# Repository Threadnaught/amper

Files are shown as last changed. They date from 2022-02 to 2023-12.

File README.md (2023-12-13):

# Amper

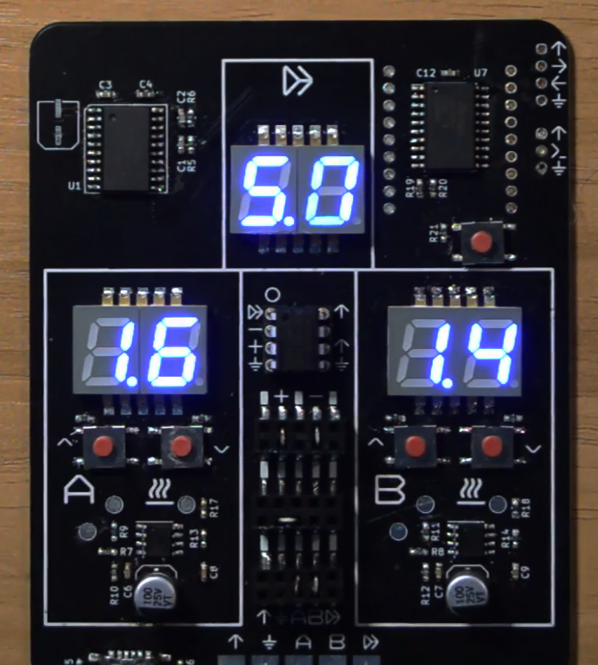
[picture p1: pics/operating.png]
Operating


I'm unprivating my amper project for posterity. At time of writing, a lot of the code looks commented out and it's been like two years so I dare not go back in now. It's got two basic functions:

1. A learning tool for Op-Amps allowing you to set two voltage rails and create a circuit on the breadboard-like arangement of headers in the middle.
2. A (somewhat bad) dual rail switch mode lab supply

1 worked relatively well. Turns out pin headers are designed more for du-pont style pins than resistor or capacitor legs.

Regarding 2, This project taught me a lesson: don't use a microcontroller to manage power rails unless you really know what you're doing. There are many things which can raise input impeadance too fast for a UC to notice, and then the rail will spike to supply voltage.

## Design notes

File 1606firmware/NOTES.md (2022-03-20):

 - https://github.com/ElTangas/jtag2updi
 - AVR-GCC
 - http://packs.download.atmel.com/ grab `Atmel ATtiny Series Device Support (1.10.348)`
 - Follow this tutorial http://leonerds-code.blogspot.com/2020/11/building-for-new-atmega-0-series-chips.html
 - MAY ALSO HAVE TO DO THE `/usr/avr/include/avr/io.h` STEP FROM THIS ONE https://gist.github.com/goncalor/51e1c8038cc058b4379552477255b4e1

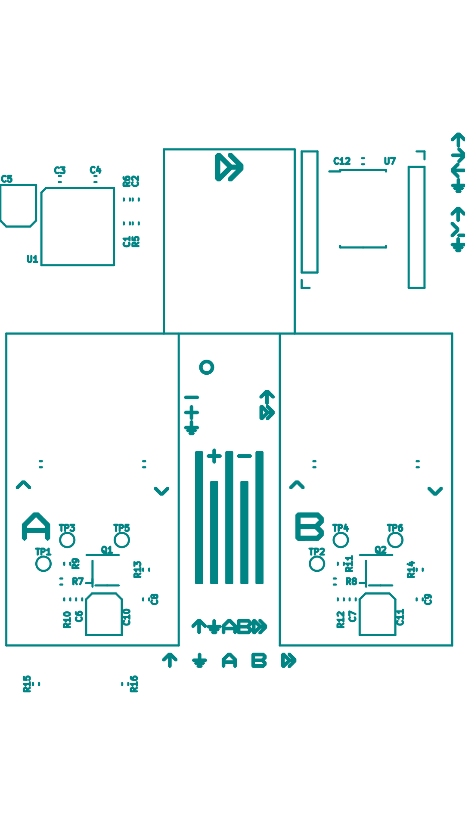
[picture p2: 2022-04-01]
kicad/pcb-plots/amper-F_SilkS.png

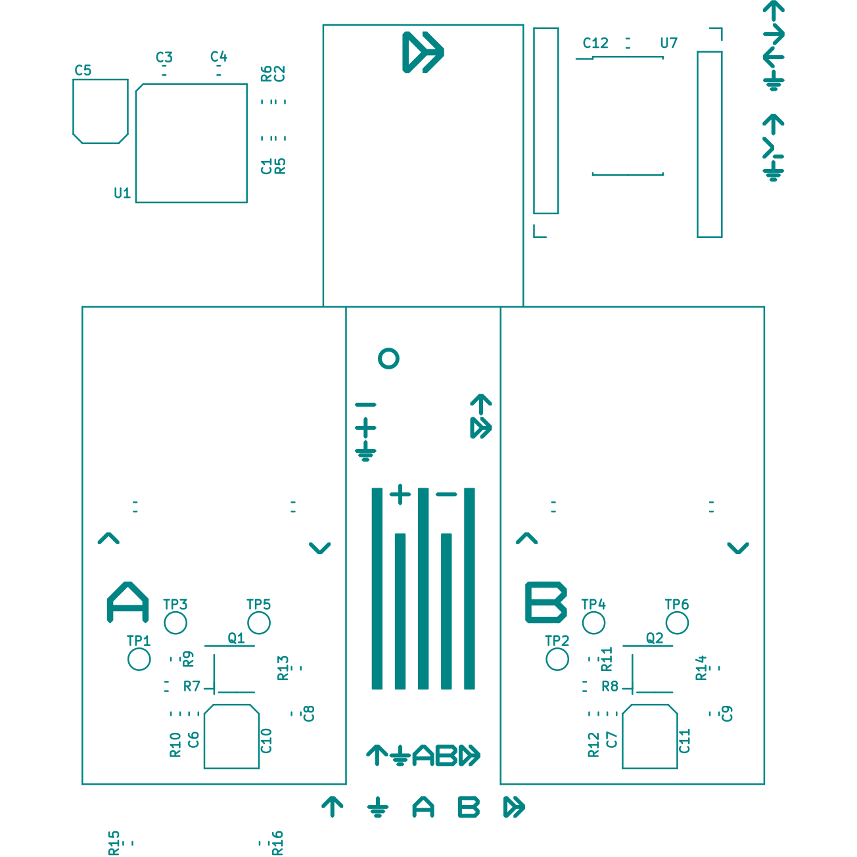
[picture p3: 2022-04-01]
kicad/pcb-plots/amper-F_SilkS-square.png

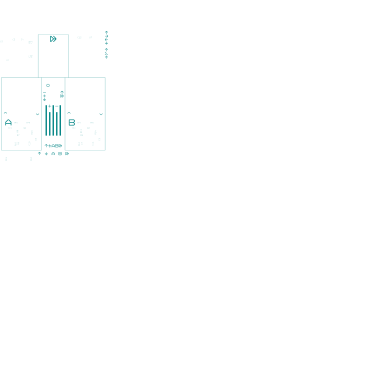
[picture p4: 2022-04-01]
kicad/pcb-plots/outp.png

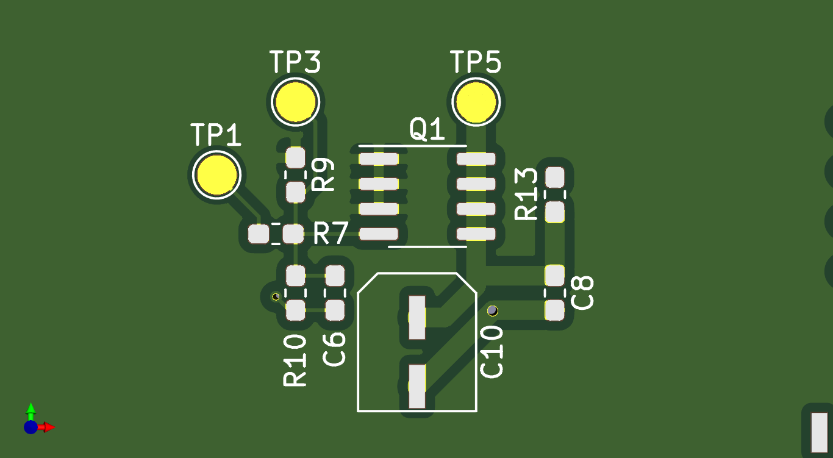
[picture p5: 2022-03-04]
kicad/amper/amper.png

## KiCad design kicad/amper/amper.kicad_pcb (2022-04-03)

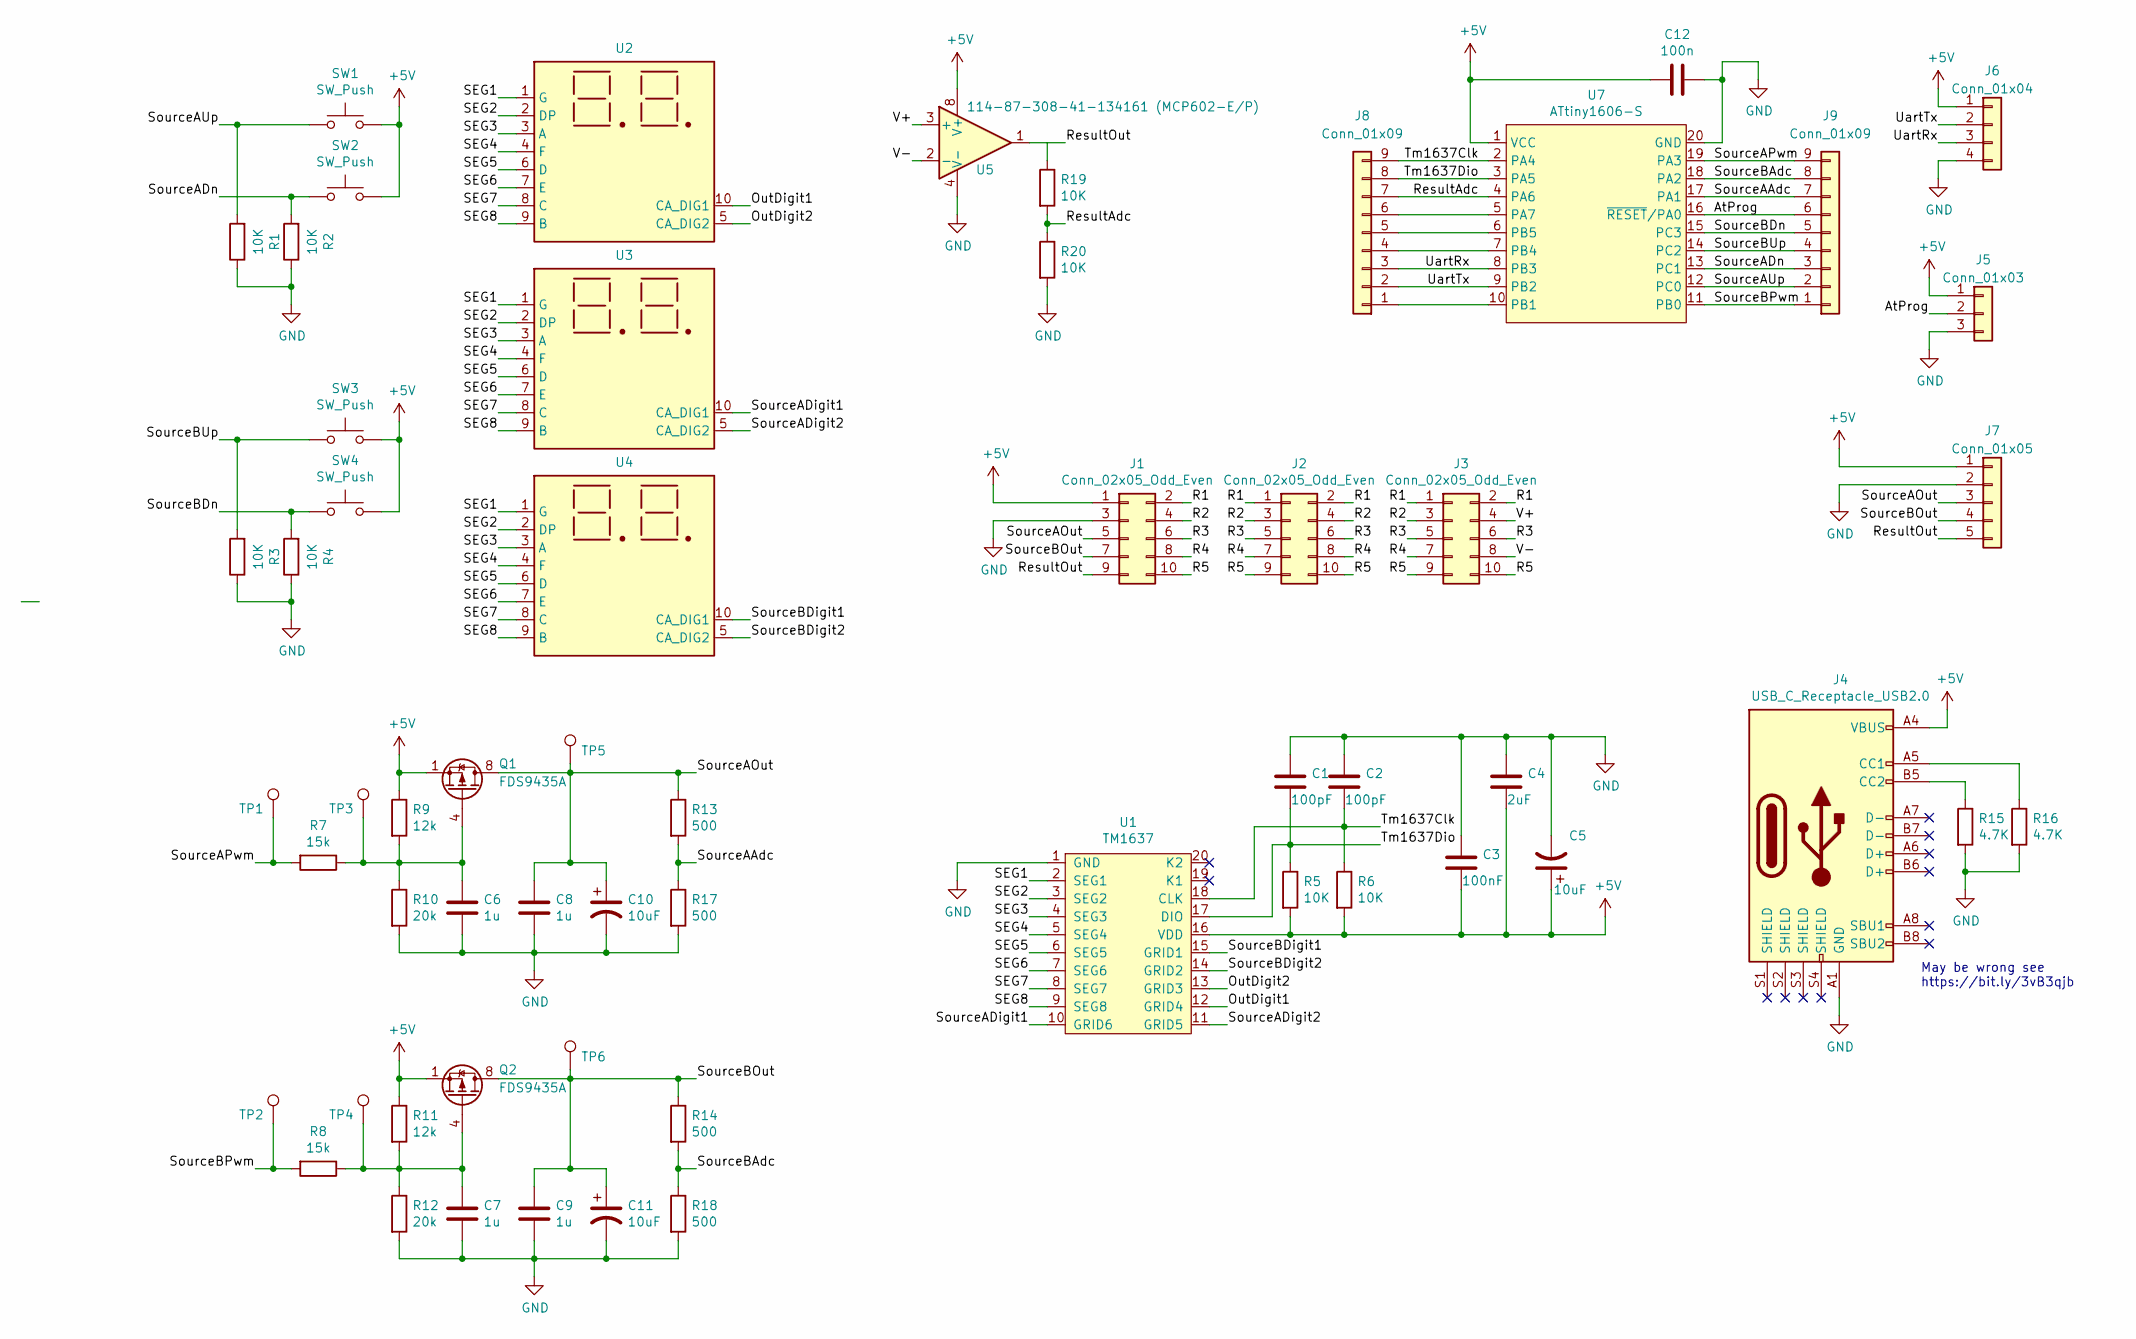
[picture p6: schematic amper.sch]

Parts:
C1, C2: 100pF; C_0603_1608Metric_Pad1.05x0.95mm_HandSolder
C3: 100nF; C_0603_1608Metric_Pad1.05x0.95mm_HandSolder
C4: 2uF; C_0603_1608Metric_Pad1.05x0.95mm_HandSolder; Part C85713
C5, C10, C11: 10uF; VT1H100M-CRD54; Part C305359
C6, C7, C8, C9: 1u; C_0603_1608Metric_Pad1.05x0.95mm_HandSolder
C12: 100n; C_0603_1608Metric_Pad1.05x0.95mm_HandSolder
J1: Conn_02x05_Odd_Even; 2.54_2x5_alternate-source-side
J2: Conn_02x05_Odd_Even; 2.54_2x5_alternate
J3: Conn_02x05_Odd_Even; 2.54_2x5_alternate-opamp-side
J4: USB_C_Receptacle_USB2.0; MC-303S
J5: Conn_01x03; PROG
J6: Conn_01x04; UART
J7: Conn_01x05; SolderHeader
J8, J9: Conn_01x09; PinSocket_1x09_P2.54mm_Vertical_no_silk
Q1, Q2: FDS9435A; SOIC-8_3.9x4.9mm_P1.27mm; Part C181098
R1, R2, R3, R4, R5, R6, R19, R20: 10K; R_0603_1608Metric_Pad1.05x0.95mm_HandSolder
R7, R8: 15k; R_0603_1608Metric_Pad1.05x0.95mm_HandSolder
R9, R11: 12k; R_0603_1608Metric_Pad1.05x0.95mm_HandSolder
R10, R12: 20k; R_0603_1608Metric_Pad1.05x0.95mm_HandSolder
R13, R14, R17, R18: 500; R_0603_1608Metric_Pad1.05x0.95mm_HandSolder
R15, R16: 4.7K; R_0603_1608Metric_Pad1.05x0.95mm_HandSolder
SW1, SW3: SW_Push; UpSwitch; Part C2909692
SW2, SW4: SW_Push; DnSwitch; Part C2909692
TP1, TP2, TP3, TP4, TP5, TP6: TestPoint; TestPoint_Pad_D2.0mm
U1: TM1637; Part C20001
U2, U3, U4: HDSM-441B; SLS0392FB4A1GD; Part C226000
U5: 114-87-308-41-134161 (MCP602-E/P); 114-87-308-41-134161-generated
U7: ATtiny1606-S; SOIC-20W_7.5x12.8mm_P1.27mm

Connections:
+5V: C3.2, C4.2, C5.1, C12.2, J1.1, J4.A4 (VBUS), J4.A9 (VBUS), J4.B4 (VBUS), J4.B9 (VBUS), J5.1, J6.1, J7.1, Q1.1 (S), Q1.2 (S), Q1.3 (S), Q2.1 (S), Q2.2 (S), Q2.3 (S), R5.2, R6.2, R9.1, R11.1, SW1.2, SW2.2, SW3.2, SW4.2, U1.16 (VDD), U5.6 (NULL), U5.8 (V+), U7.1 (VCC)
/AtProg: J5.2, J9.6, U7.16 (~RESET~/PA0)
/OutDigit1: U1.12 (GRID4), U2.10 (CA_DIG1)
/OutDigit2: U1.13 (GRID3), U2.5 (CA_DIG2)
/R1: J1.2, J2.1, J2.2, J3.1, J3.2
/R2: J1.4, J2.3, J2.4, J3.3
/R3: J1.6, J2.5, J2.6, J3.5, J3.6
/R4: J1.8, J2.7, J2.8, J3.7
/R5: J1.10, J2.9, J2.10, J3.9, J3.10
/ResultAdc: J8.7, R19.2, R20.1, U7.4 (PA6)
/ResultOut: J1.9, J7.5, R19.1, U5.1
/SEG1: U1.2 (SEG1), U2.1 (G), U3.1 (G), U4.1 (G)
/SEG2: U1.3 (SEG2), U2.2 (DP), U3.2 (DP), U4.2 (DP)
/SEG3: U1.4 (SEG3), U2.3 (A), U3.3 (A), U4.3 (A)
/SEG4: U1.5 (SEG4), U2.4 (F), U3.4 (F), U4.4 (F)
/SEG5: U1.6 (SEG5), U2.6 (D), U3.6 (D), U4.6 (D)
/SEG6: U1.7 (SEG6), U2.7 (E), U3.7 (E), U4.7 (E)
/SEG7: U1.8 (SEG7), U2.8 (C), U3.8 (C), U4.8 (C)
/SEG8: U1.9 (SEG8), U2.9 (B), U3.9 (B), U4.9 (B)
/SourceAAdc: J9.7, R13.2, R17.1, U7.17 (PA1)
/SourceADigit1: U1.10 (GRID6), U3.10 (CA_DIG1)
/SourceADigit2: U1.11 (GRID5), U3.5 (CA_DIG2)
/SourceADn: J9.3, R2.2, SW2.1, U7.13 (PC1)
/SourceAOut: C8.1, C10.1, J1.5, J7.3, Q1.5 (D), Q1.6 (D), Q1.7 (D), Q1.8 (D), R13.1, TP5.1
/SourceAPwm: J9.9, R7.2, TP1.1, U7.19 (PA3)
/SourceAUp: J9.2, R1.2, SW1.1, U7.12 (PC0)
/SourceBAdc: J9.8, R14.2, R18.1, U7.18 (PA2)
/SourceBDigit1: U1.15 (GRID1), U4.10 (CA_DIG1)
/SourceBDigit2: U1.14 (GRID2), U4.5 (CA_DIG2)
/SourceBDn: J9.5, R4.2, SW4.1, U7.15 (PC3)
/SourceBOut: C9.1, C11.1, J1.7, J7.4, Q2.5 (D), Q2.6 (D), Q2.7 (D), Q2.8 (D), R14.1, TP6.1
/SourceBPwm: J9.1, R8.2, TP2.1, U7.11 (PB0)
/SourceBUp: J9.4, R3.2, SW3.1, U7.14 (PC2)
/Tm1637Clk: C2.2, J8.9, R6.1, U1.18 (CLK), U7.2 (PA4)
/Tm1637Dio: C1.2, J8.8, R5.1, U1.17 (DIO), U7.3 (PA5)
/UartRx: J6.3, J8.3, U7.8 (PB3)
/UartTx: J6.2, J8.2, U7.9 (PB2)
/V+: J3.4, U5.3 (+)
/V-: J3.8, U5.2 (-)
GND: C1.1, C2.1, C3.1, C4.1, C5.2, C6.2, C7.2, C8.2, C9.2, C10.2, C11.2, C12.1, J1.3, J4.A1 (GND), J4.A12 (GND), J4.B1 (GND), J4.B12 (GND), J5.3, J6.4, J7.2, R1.1, R2.1, R3.1, R4.1, R10.2, R12.2, R15.2, R16.2, R17.2, R18.2, R20.2, U1.1 (GND), U5.4 (V-), U5.5 (NULL), U7.20 (GND)
unnamed: C6.1, Q1.4 (G), R7.1, R9.2, R10.1, TP3.1
unnamed: C7.1, Q2.4 (G), R8.1, R11.2, R12.1, TP4.1
unnamed: J4.A5 (CC1), R16.1
unnamed: J4.B5 (CC2), R15.1
unnamed: J8.1, U7.10 (PB1)
unnamed: J8.4, U7.7 (PB4)
unnamed: J8.5, U7.6 (PB5)
unnamed: J8.6, U7.5 (PA7)

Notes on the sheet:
May be wrong see https://bit.ly/3vB3qjb

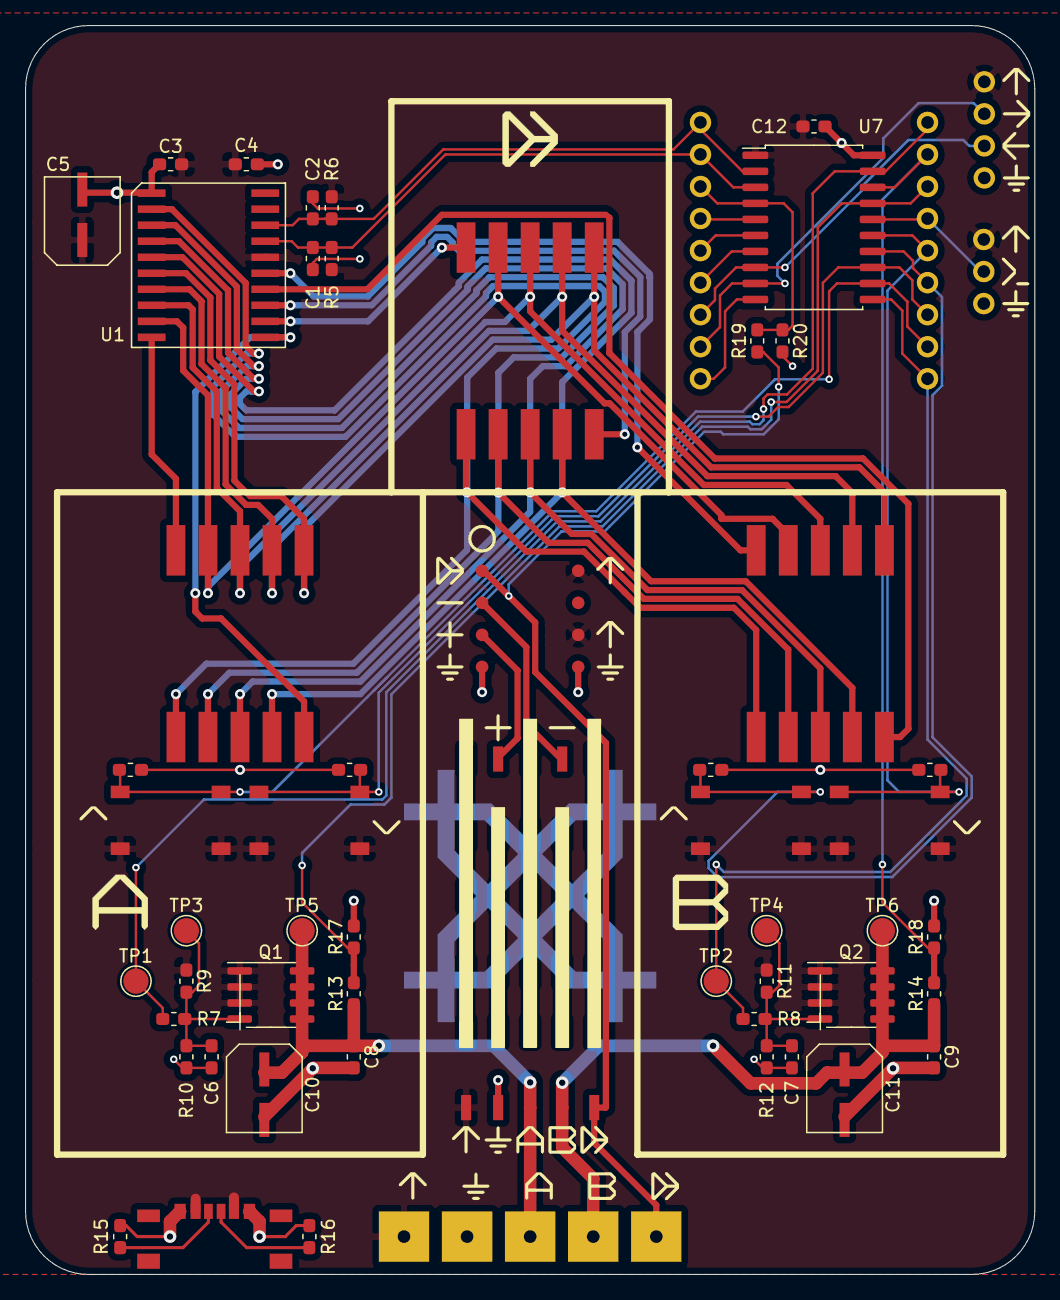
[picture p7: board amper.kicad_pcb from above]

Board: 2 copper layers, 80.0 x 99.0 mm, 63 parts (1 on the bottom side), 48 nets.

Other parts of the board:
svg2mod: G***; pcb_logo_small
svg2mod#2: G***; LargeOutput
svg2mod#3: G***; LargeB
svg2mod#4: G***; LargeA

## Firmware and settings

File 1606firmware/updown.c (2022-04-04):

#ifndef __AVR_ATtiny1606__
#define __AVR_ATtiny1606__
#endif

#include "./chars.h"
#include "./constants.h"

#include <inttypes.h>
#include <avr/io.h>
#include <util/delay.h>

#define SOURCE_A_OUT_ADC ADC_MUXPOS_AIN1_gc
#define SOURCE_B_OUT_ADC ADC_MUXPOS_AIN2_gc
#define RESULT_ADC ADC_MUXPOS_AIN6_gc

inline void uartPutChar(char c){
	while (!(USART0.STATUS & USART_DREIF_bm));
	USART0.TXDATAL = c;
}
inline void uartPutProgmemStr(const char* pgstr){
	for(size_t i = 0; pgm_read_byte(&pgstr[i]) != 0; i++)
		uartPutChar(pgm_read_byte(&pgstr[i]));
}
//The fact that arabic numerals come out msb first must have been created specifically to annoy me
inline void uartPutHexByte(unsigned char val){
	for(long i = 4; i >= 0; i -= 4){
		unsigned char cursor = 0x0F << i;
		unsigned char cur = (val & cursor) >> i;
		if(cur >= 10){
			uartPutChar('A' + cur - 10);
		} else {
			uartPutChar('0' + cur);
		}
	}
}

inline void uartPutHexUInt(unsigned long val, int32_t bytes){
	unsigned char* cast = (unsigned char*)&val;
	for(int32_t i = bytes-1; i >= 0; i--)
		uartPutHexByte(cast[i]);
}

inline void uartPutHexInt(long val, int32_t bytes){
	if(val < 0){
		uartPutChar('-');
		val = -val;
	}
	uartPutHexUInt(val, bytes);
}

//Set the pinmode of TM1637_CLK and TM1637_DIO
//Output mode (1) has side effect of reducing impedance to GND and so drives the pin LOW
//Input mode (0) allows pin to be pulled HIGH by external resistors
static inline void Tm1637Set(unsigned char ClkMode, unsigned char DioMode){
	if(ClkMode)
		PORTA_DIR &= ~(1 << TM1637_CLK);
	else
		PORTA_DIR |= (1 << TM1637_CLK);
	if(DioMode)
		PORTA_DIR &= ~(1 << TM1637_DIO);
	else
		PORTA_DIR |= (1 << TM1637_DIO);
	_delay_us(TM1637_CLOCK_US);
}

//start and stop a TM1637 transaction around a block of code
#define txn(a) { \
	Tm1637Set(1, 0); \
	a \
	Tm1637Set(0,0);\
	Tm1637Set(1,0);\
	Tm1637Set(1,1);\
}

//Bang b out to the TM1637
void sendByte(unsigned char b){
	for(unsigned char i = 0; i < 8; i++) {
		Tm1637Set(0,1);
		unsigned char bit = b & 0b00000001;
		Tm1637Set(0,bit);
		Tm1637Set(1,bit);
		b >>= 1;
	}
	Tm1637Set(0,1);
	Tm1637Set(1,1);
	Tm1637Set(0,0);
}

//Assumes segs is TM1637_DIGITS bytes long
void sendSegs(const unsigned char* segs){
	txn({
		sendByte(TM1637_ADDRESS);
		for(unsigned char i = 0; i < TM1637_DIGITS; i++){
			// sendByte(segs[i]);
			sendByte(segs[pgm_read_byte(&segmentOrder[i])]);
		}
	});
}

void intToTwoSegs(int32_t i, unsigned char* segs, int32_t tenths){
	segs[1] 
		= pgm_read_byte(chars +'0' + (i%10));
	i /= 10;
	segs[0] 
		= pgm_read_byte(chars +'0' + (i%10))
		| (tenths ? pgm_read_byte(chars +'.') : 0);
}

inline void handleButtons(int32_t i, unsigned char up_mask, unsigned char down_mask, unsigned char* voltages){
	if(PORTC_IN & up_mask){
		voltages[i] = MIN(MAX_V, voltages[i]+1);
	}
	if(PORTC_IN & down_mask){
		voltages[i] = MAX(0, voltages[i]-1);
	}
}

inline unsigned short adcRawCounts(unsigned char muxpos){
	ADC0_MUXPOS = muxpos;

	ADC0_COMMAND = 0x01;

	while(ADC0_COMMAND);

	// uartPutProgmemStr(PSTR("ADC Result:")); uartPutHexUInt(ADC0_RES, 2); uartPutChar('\n');
	return MIN(ADC0_RES, 0x03FF);
}

//TODO: calibration
inline unsigned short adcTenthsVolt(unsigned short counts){
	return DIV_ROUND((counts << 5), ADC_CONVERSION_CONSTANT);
}

inline unsigned short tenthsVoltRawCount(unsigned short tenths){
	return (tenths * ADC_CONVERSION_CONSTANT) >> 5;
}

void initRegs(){
	const struct reg* r = regs;
	while(1){
		struct reg cur;
		memcpy_P(&cur, r, sizeof(struct reg));
		switch(cur.size){
			case 0:
				return;
			case 8:
				*((volatile uint8_t*)cur.target) = (uint8_t)cur.val;
				break;
			case 16:
				*((volatile uint16_t*)cur.target) = (uint16_t)cur.val;
				break;
			case 32:
				*((volatile uint32_t*)cur.target) = (uint32_t)cur.val;
				break;
		}
		r++;
	}
}

void handlePwm(unsigned char* voltage, short* pwmOutput, unsigned char adcMuxPos){
	unsigned short target = tenthsVoltRawCount(*voltage);
	unsigned short counts = adcRawCounts(adcMuxPos);
	if(counts > target && (*pwmOutput) < pwmMax){
		(*pwmOutput)++;
	} else if (counts < target && (*pwmOutput) > 0) {
		(*pwmOutput)--;
	}
}

void main(){
	//Set clock to maximum (20 MHz)
	_PROTECTED_WRITE(CLKCTRL.MCLKCTRLB, 0);

	initRegs();

	uartPutProgmemStr(PSTR("Set up regs\n"));

	int32_t sourceATargetTenths = 30;
	int32_t sourceAPwm = pwmMax;
	TCA0_SPLIT_HCMP0 = sourceAPwm >> pwmShift;
	// TCA0_SPLIT_LCMP0 = 0;
	
	
	while(1){
		int32_t sourceATargetRaw = tenthsVoltRawCount(sourceATargetTenths);
		int32_t sourceAAdc = adcRawCounts(SOURCE_A_OUT_ADC);

		int32_t error = sourceAAdc - sourceATargetRaw;
		
		// if(error > 0){
		// 	uartPutProgmemStr(PSTR("Too high\n"));
		// } else if (error < 0){
		// 	uartPutProgmemStr(PSTR("Too low\n"));
		// }

		
		// uartPutProgmemStr(PSTR("\nerror:")); uartPutHexInt(error, 4); uartPutProgmemStr(PSTR("\n"));

		sourceAPwm += error;
		// uartPutProgmemStr(PSTR("sourceAPwm:")); uartPutHexInt(sourceAPwm, 4); uartPutProgmemStr(PSTR("\n"));
		
		if(sourceAPwm < 0)
			sourceAPwm = 0;
		if(sourceAPwm > pwmMax)
			sourceAPwm = pwmMax;
		
		// uartPutProgmemStr(PSTR("sourceAPwm:")); uartPutHexInt(sourceAPwm, 4); uartPutProgmemStr(PSTR("\n"));
		TCA0_SPLIT_HCMP0 = sourceAPwm >> pwmShift;

		// _delay_ms(100);
	}

	// while(1){
	// 	uartPutProgmemStr(PSTR("Asdf\n"));
	// 	_delay_ms(25);
	// }

	// unsigned char voltages[] = { 10, 10, 10 };
	// short pwmOutputs[] = {pwmMax, pwmMax};
	// unsigned char segments[6];

	// int32_t loops = 0;

	// //Turn display on and set TM1637_BRIGHTNESS
	// Tm1637Set(1,1);
	// txn({
	// 	sendByte(TM1637_DATA);
	// });
	// txn({
	// 	sendByte( TM1637_DISPLAY				//command
	// 			| 0x08						//display is on
	// 			| (TM1637_BRIGHTNESS & 0x07)); 	//set TM1637_BRIGHTNESS
	// });

	// while(1){
	// 	// int32_t counts = adcRawCounts(SOURCE_B_OUT_ADC);
		
	// 	for(int32_t i = 0; i < 3; i++){
	// 		intToTwoSegs(voltages[i], segments + (i*2), 1);
	// 	}


	// 	if((loops++) % 300 == 0) {

	// 		handleButtons(0, PIN0_bm, PIN1_bm, voltages);
	// 		handleButtons(1, PIN2_bm, PIN3_bm, voltages);
	// 		voltages[2] = adcTenthsVolt(adcRawCounts(RESULT_ADC));
	// 		sendSegs(segments);

	// 		// uartPutProgmemStr(PSTR("Counts:")); uartPutHexUInt(counts, 4); uartPutChar('\n');
	// 		// uartPutProgmemStr(PSTR("Target:")); uartPutHexUInt(target, 4); uartPutChar('\n');
	// 		// uartPutProgmemStr(PSTR("PWM:")); uartPutHexUInt(pwmOutputs[1], 4); uartPutChar('\n');

	// 		// uartPutChar('\n');
	// 	}

	// 	handlePwm(&voltages[0], &pwmOutputs[0], SOURCE_A_OUT_ADC);
	// 	handlePwm(&voltages[1], &pwmOutputs[1], SOURCE_B_OUT_ADC);
	// 	TCA0_SPLIT_HCMP0 = pwmOutputs[0]>>pwmShift;
	// 	TCA0_SPLIT_LCMP0 = pwmOutputs[1]>>pwmShift;
		
	// 	// _delay_ms(25);
	// }
}

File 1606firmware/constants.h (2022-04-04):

#ifndef __AVR_ATtiny1606__
#define __AVR_ATtiny1606__
#endif

#include <avr/pgmspace.h>
#include <avr/io.h>
#include <inttypes.h>

struct reg{
	volatile void* target;
	uint8_t size;
	uint32_t val;
};

#define F_CPU 20000000UL

#define BAUDRATE 9600
#define BAUD_REG (uint16_t)((float)(F_CPU * 64 / (16 *(float)BAUDRATE)) + 0.5)

//TM1637:
#define TM1637_DATA	0x40
#define TM1637_ADDRESS	0xC0
#define TM1637_DISPLAY	0x80
#define TM1637_CLOCK_US 1 //10 is a safe value
#define TM1637_BRIGHTNESS 0x00 //0x00 - 0x0f
#define TM1637_CLK PIN4
#define TM1637_DIO PIN5
#define TM1637_DIGITS 6

const unsigned char segmentOrder[6] PROGMEM = {2,3,5,4,1,0};

// where max voltage is in tenths:
// measured value / (max value / max voltage)
// = (measured value << 5) / ((max value <<	5) / max voltage)
// = (measured value << 5) / ((0x3FF << 5) / 43)
// ~= (measured value << 5) / 0x02F9
#define ADC_CONVERSION_CONSTANT 0x02F9

#define MAX_V 43
#define MIN_V 0
#define pwmShift 10
#define pwmMax ((int32_t)127) <<pwmShift

//util funcs:
#define MAX(a,b) (a>b)?a:b
#define MIN(a,b) (a<b)?a:b
#define DIV_ROUND(a,b) (a + (b/2))/b

const struct reg regs[] PROGMEM = {
	//setup pin directions;
	{&PORTA_DIR, 8, PIN3_bm},
	{&PORTB_DIR, 8, PIN0_bm | PIN2_bm},
	{&PORTC_DIR, 8, 0x00},
	//UART setup:
	{&USART0_BAUD, 16, BAUD_REG},
	{&USART0_CTRLC, 8, USART_CHSIZE0_bm | USART_CHSIZE1_bm},
	{&USART0_CTRLB, 8, USART_TXEN_bm},//enable always last
	//ADC setup:
	{&VREF_CTRLA, 8, VREF_ADC0REFSEL_4V34_gc},
	{&ADC0_CTRLB, 8, 0x00},
	{&ADC0_CTRLC, 8, ADC_PRESC0_bm | ADC_PRESC1_bm | ADC_PRESC2_bm},
	{&ADC0_CTRLD, 8, 0x00},
	{&ADC0_CTRLE, 8, 0x00},
	{&ADC0_CALIB, 8, ADC_DUTYCYC_bm},
	{&ADC0_CTRLA, 8, ADC_ENABLE_bm},//enable always last
	//PWM setup:
	{&TCA0_SINGLE_CTRLD, 8, TCA_SINGLE_SPLITM_bm},
	{&TCA0_SPLIT_LPER, 8, 127},
	{&TCA0_SPLIT_HPER, 8, 127},
	{&TCA0_SPLIT_LCMP0, 8, 127},
	{&TCA0_SPLIT_HCMP0, 8, 127},
	{&TCA0_SPLIT_CTRLB, 8, TCA_SPLIT_HCMP0EN_bm | TCA_SPLIT_LCMP0EN_bm},
	{&TCA0_SPLIT_CTRLA, 8, TCA_SPLIT_ENABLE_bm},//enable always last
	//Terminate:
	{0x00, 0, 0x00},
};

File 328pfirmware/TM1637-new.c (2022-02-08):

#ifndef __AVR_ATmega328P__
  #define __AVR_ATmega328P__
#endif

#define F_CPU 20000000UL
#include <inttypes.h>
#include <avr/io.h>
#include <util/delay.h>

#include "./chars.h"

#define LED_DATA	0x40
#define LED_ADDRESS	0xC0
#define LED_DISPLAY	0x80
#define DATA_CLOCK_US 100

//0x00 - 0x0f
#define BRIGHTNESS 0x00
// #define BRIGHTNESS 0x0f

#define CLK PD4
#define DIO PD5

#define DIGITS 6

//Set the pinmode of CLK and DIO
//Output mode (1) has side effect of reducing impedance to GND and so drives the pin LOW
//Input mode (0) allows pin to be pulled HIGH by external resistors
static inline void SetClkDioMode(unsigned char ClkMode, unsigned char DioMode){
	if(ClkMode)
		DDRD &= ~(1 << CLK);
	else
		DDRD |=	(1 << CLK);
	if(DioMode)
		DDRD &= ~(1 << DIO);
	else
		DDRD |=	(1 << DIO);
	_delay_us(DATA_CLOCK_US);
}

//start and stop a TM1637 transaction around a block of code
#define txn(a) { \
	SetClkDioMode(1, 0); \
	a \
	SetClkDioMode(0,0);\
	SetClkDioMode(1,0);\
	SetClkDioMode(1,1);\
}

//Bang b out to the TM1637
void sendByte(unsigned char b){
	for(unsigned char i = 0; i < 8; i++) {
		SetClkDioMode(0,1);
		unsigned char bit = b & 0b00000001;
		SetClkDioMode(0,bit);
		SetClkDioMode(1,bit);
		b >>= 1;
	}
	SetClkDioMode(0,1);
	SetClkDioMode(1,1);
	SetClkDioMode(0,0);
}

//Assumes segs is DIGITS bytes long
void sendSegs(const unsigned char* segs){
	txn({
		sendByte(LED_ADDRESS);
		for(unsigned char i = 0; i < DIGITS; i++){
			sendByte(segs[i]);
		}
	});
}


const unsigned char segmentOrder[6] PROGMEM = {2,1,0,5,4,3};

// unsigned char ascii[] = { 0x30+5, 0x31+5, 0x32+5, 0x33+5, 0x34+5, 0x35+5 };
unsigned char vals[] = { 0x00, 0x01, 0x02, 0x03, 0x04, 0x05 };

unsigned char segments[6];

void main(){
	SetClkDioMode(1,1);
	//Turn display on and set brightness
	txn({
		sendByte(LED_DATA);
	});
	txn({
		sendByte( LED_DISPLAY				//command
				| 0x08						//display is on
				| (BRIGHTNESS & 0x07)); 	//set brightness
	});
	while(1){
		for(int i = 0; i < 6; i++) {
			//assign in segment order
			segments[pgm_read_byte(&segmentOrder[i])]
			//lookup ascii in PROGMEM
			 	= pgm_read_byte(&chars[vals[i] + 0x30]);
			vals[i] = (vals[i]+1)%10;
		}
		// All segments on
		sendSegs(segments);
		_delay_ms(100);
	}
}

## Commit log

2022-01-03 finished amper first version
    [amper.kicad_pcb, amper.sch]
2022-01-05 amper rev a
    [amper.kicad_pcb, amper.sch]
2022-01-06 Amper rev A ready to go
    [amper.kicad_pcb, amper.sch]
2022-02-23 added easy fixes from testing to sch
    [amper.sch]
2022-02-23 added attiny1606
    [amper.sch]
2022-02-23 netlist rename pass
    [amper.sch]
2022-02-23 added all connections from Amper 1606 port assignment in GDrive
    [amper.sch]
2022-02-24 added breakout headers
    [amper.sch]
2022-02-28 fixed library
    [amper.sch]
2022-03-01 created new footprint for opamp breakout
2022-03-02 added solderable header + symbols
    [amper.sch]
2022-03-03 Added new footprints for fat capacitor and usb-c socket
    [amper.sch]
2022-03-03 Added mini breadboard
    [amper.sch]
2022-03-03 ready for PCB layout
    [amper.sch]
2022-03-04 Reannotated everything
    [amper.kicad_pcb, amper.sch]
2022-03-04 most of the large components in place, started laying tracks
    [amper.kicad_pcb, amper.sch]
2022-03-05 Layed out symetrical 7 seg and driver circuits
    [amper.kicad_pcb, amper.sch]
2022-03-05 added symbols, Routed very centre of board
    [amper.kicad_pcb, amper.sch]
2022-03-05 New layout with boxes
    [amper.kicad_pcb, amper.sch]
2022-03-05 Added USB socket and boxes with A, B and output symbols. Local routing started
    [amper.kicad_pcb, amper.sch]
2022-03-05 Added some very cool segment routing if I do say so myself
    [amper.kicad_pcb]
2022-03-05 Added grid routing
    [amper.kicad_pcb, amper.sch]
2022-03-06 Electrically connected, still needs some work
    [amper.kicad_pcb, amper.sch]
2022-03-06 misc corrections
    [amper.kicad_pcb, amper.sch]
2022-03-06 almost finished first path at board rev b, still a little work to do around logos, text and plane continuity
    [amper.kicad_pcb, amper.sch]
2022-03-06 Fixed a few issues, Ready for checking stage
    [amper.kicad_pcb]
2022-03-20 rev B as fabbed
    [amper.sch]
2022-03-20 Added ADC code, butttons and integer comparison
2022-03-27 minimum viable power supply (single rail)
2022-03-28 Ready for rev c
    [amper.kicad_pcb]
2022-03-29 Updated power supplies to schematic, reorganised schematic
    [amper.sch]
2022-04-01 moved components to make better use of schematic
    [amper.kicad_pcb, amper.sch]
2022-04-01 Updated opamp
    [amper.sch]
2022-04-01 high level schematic changes completed
    [amper.sch]
2022-04-03 Rev C appears finished, going to sleep on it
    [amper.kicad_pcb, amper.sch]
2022-04-04 added proportional error based feedback
    [constants.h, updown.c]
